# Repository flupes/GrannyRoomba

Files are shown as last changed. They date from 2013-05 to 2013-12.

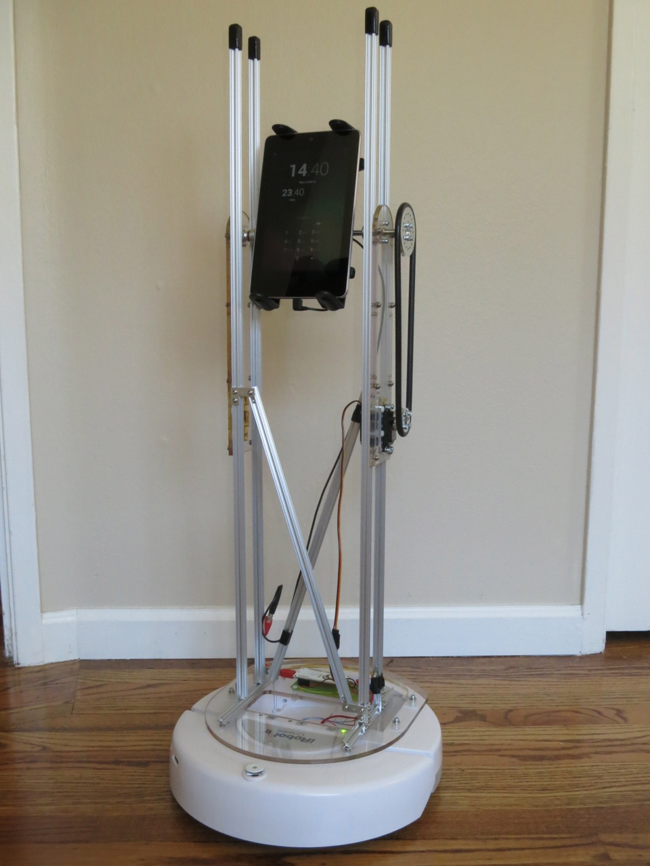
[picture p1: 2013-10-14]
hw/pics_2013-10-14/gr_overview.jpg

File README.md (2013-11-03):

GrannyRoomba or Telepresence Roomba for Grandma
===============================================

The idea of this project is to develop a simple and inexpensive telepresence robot to improve the Skype experience of a grandmother with her grandchild.

On Columbus Day 2013, the system performed successfully a first robotic video conference from France to California!
The system still need improvements, but the concepts are in place.

Quick facts:
  - The mobile base uses a [Roomba Create](http://www.irobot.com/us/learn/Educators/Create.aspx)
  - The custom super-structure uses a tilt mechanism actuated with a servo
  - Nexus-7 Android (gen 1) tablet runs the robot software
  - [IOIO-OTG](https://github.com/ytai/ioio/wiki) board interfaces the tablet with the hardware
  - Messaging is defined using Google [Protocol Buffers](https://developers.google.com/protocol-buffers/)
  - Communication relies on the [ZeroMQ](http://zeromq.org/) library (more precisely [JeroMQ](https://github.com/zeromq/jeromq))

You can look at some pics from the [Wiki page](https://github.com/flupes/GrannyRoomba/wiki/GrannyRoomba-Wiki-Home).

History of this project is available in the [project.org](https://github.com/flupes/GrannyRoomba/blob/master/project.org) file.

License:
  - The software part (code) of GrannyRoomba is released under [GPLv3](http://www.gnu.org/licenses/gpl-3.0-standalone.html).
  - The hardware part (drawings, electronics, etc.) is released under a <a rel="license"
    href="http://creativecommons.org/licenses/by-sa/3.0/deed.en_US">Creative
    Commons Attribution-ShareAlike 3.0 Unported License</a>

Do you want to help? Do you like the name or find it ridiculous? Contact me!

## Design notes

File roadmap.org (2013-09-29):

* Iteration 1: proof of concept
** Goal
   Obtain a system that allows to command wirelessly the Roomba and Tilt-Servo from
   the PC, this while running Skype on the tablet.
** Work items
*** DONE Create a basic serial "driver" to command the Roomba
*** DONE Test a IOIO Service running together with Skype
*** DONE Setup and read the telemetry from the Roomba
*** DONE Test commanding Roomba from IOIO
*** DONE Build and test ZeroMQ from PC to Android
*** DONE Use slf4j for logging with implementation of log4j on PC and slf4j-android on Android
*** DONE Configure and test JeroMQ on PC and on Android
*** DONE Create a board to power the IOIO from the Roomba and provide communication lines
*** DONE Find a realistic Android debug solution with the IOIO
    - System for Android Virtual Device that works:
      - use IOIO bridge to allow the AVD talk to the IOIO connected to the PC
      - use adb port forwarding to bridge the localhost port required by
        zeromq to the AVD
      - use regular ADB to debug
    - Still no success using the Nexus-7:
      - it should work with ADB over wifi and using the IOIO as an
        Open-Accessory device, but the way I trigger ADB over wifi still
        requires "USB Debug" enabled... I think the Nexus need to be
        rooted to go otherwise
*** DONE Create protocol-buffer messages to support Locomotion and SingleAxis commands
*** DONE Create framework to run the client / server system
*** DONE Create the clients and servers for locomotion and single axis
*** DONE Create a Eclipse workspace where JeroMQ, slf4j, IOIO, the generic part of the project code and the specific Android app code is happy
*** DONE Create a simple UI to command the robot (keyboard based)
*** DONE Create a framework to start the GrannyRoomba controller as a Android Service
* Iteration 2: stabilize the system and fill huge gaps
** Goal
   Make the system more usable, mostly by working on the lifecycle of the
   application. Some critical features also need to be implemented to
   avoid breaking the Roomba: bump detection (and position drive to backup)
** Work items
*** TODO Implement position drive
*** TODO Implement safe guarded locomotion (using bumpers)
*** TODO Refine the start/stop of the system and lifecyle of the GrannyRoomba servive
* Iteration 3: clean up the system and document
* Iteration 4: add some features
** Goal
** Work items
*** TODO Implement a joystick controller
*** TODO Create a broker service to allow bi-directional communication between to hosts, each between firewalls

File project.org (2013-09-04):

##+TITLE: GrannyRoomba Project
#+AUTHOR: Lorenzo Flueckiger
#+STARTUP: showall

* GrannyRoomba Project

** Goal
Develop a simple and cheap telepresence robot to improve the Skype
experience of a grandmother with her grandchild K.

** Rationale

K. does a video conference with his overseas Grand-Ma almost every
week. It is one way to keep this important relationship active. K. loves
to show in great details his latest creations (essentially Legos;-) and
they occasionally play roles.

We initially were doing Skype sessions with a laptop. We often had to move
the laptop from the table to the play area and back. Then we moved to
Skype on a smart-phone. This bring more mobility and allow to show better
details of the constructions. However it requires a person holding the
phone. Since K. needs his hands to manipulate toys, this role ends up to
Daddy. For this, we most of the time use the back camera to let the phone
holder point the camera precisely to the details of the action. This mode
is great for close up but we loose Grand-Ma' face. In addition, it is much
more demanding for the Dad than the laptop system which can stay
unattended for longer periods.

The system let Grand-Ma completely dependent of the skills of the phone
holder to keep up with the action and avoid to become dizzy. I knew that
Mobile Remote Presence (MRP) systems are designed to improve remote
interactions between people (see [[http://scholar.google.com/scholar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][Takayama HRI2011]] for a use case close to
this one) but was seeing this mostly as something on the fringe of my own
robotic domain. However when visiting our neighbor [[http://www.willowgarage.com/pages/research/human-robot-interaction][Willow Garage]] I
suddenly realized that I could use one of these MRP at home to have
Grand-Ma managing her own projection into K. world!

Of course, a nice professional MRP is out of my budget, but this gave me
the idea to tinker with a Roomba and an Android tablet...

** Requirements

GrannyRoomba should provide the remote user a camera with pan/tilt
controls, mounted on mobile base. The robot will only work indoors. The
tilt control is critical to offer close-up views. The pan
degree-of-freedom can be realized by the mobile base.

There should be a simple to use interface to control the various movement
of the camera, and the system should work between computers on different
networks.

The system should provide a video stream of the remote user on the
GrannyRoomba.

** Concepts

*** Computing and screen
First, I do not want to have to deal with any video and audio link between
two private homes separated by a continent plus an ocean. So the video and
audio link will still be handled by Skype or iChat/FaceTime. This implies
to use a computer system that supports well this applications, has a
screen and is lightweight. So an Android tablet (a phone screen is a little
bit too small to personalize Grand-Ma) is very tempting. A small Android
tablet like the [[http://www.google.com/nexus/7/][Nexus-7]] would provide:
 - all the necessary computing power
 - a nice screen to show Grand-Ma face
 - a camera to feed the video stream to the remote user
 - a wifi connection to connect to the home router and the rest of the world
 - extra sensors (compass and accelerometer+gyro) that we could use to
   improve the situation awareness of for the remote user
 - an open platform nice to hack

*** Robotic mobile base
Second I need a mobile base to support Grand-Ma virtual head. The height
of a MRP plays a critical role in user interactions. Unfortunately, it is
not realistic to build for this project a mobile robot that can support a 1.5m mast.
However a virtual head hovering between 30cm to 50cm from the
ground will be plenty: K. play mostly happens on the floor or on a large
shelf (what is the right word here?) 35cm height. If the action moves on a
table, K. will have to lift Grand-Ma to let her roll on the table... To
minimize the hardware work and finally use a gadget that only gather dust
in the attic, my old Roomba seems all designated for the job. This is a
pretty old [[http://www.irobot.com/us/Support/For_Home/Roomba_400_Resources/Anatomy.aspx][Roomba 400 Series, Discovery model]], that fortunately already
has the serial port socket. In theory this Roomba should provide a robust
mobile base with a nice control system documented in the
iRobot Roomba Serial Command Interface (SCI) Specification:
  - [[http://www.irobot.com/images/consumer/hacker/Roomba_SCI_Spec_Manual.pdf][broken link from iRobot]]
  - [[./refdocs/Roomba_SCI_Spec_Manual.pdf][local copy of the file]].

*Update:*
It turned out that I never could get the Roomba 400 to work, so I switched
to the iCreate (see Update section).

The Roomba Create has a different set of capabilities and access to more
internal information. The Create Open Interface is described in:
  - [[http://www.irobot.com/hrd_right_rail/create_rr/create_fam/createFam_rr_manuals.html][online version of the specification]]
  - [[./refdocs/Create_OpenInterface_v2.pdf][local copy]] just in case the iRobot link also disappears

*** Android interface with hardware
Communication between the tablet and the Roomba can happen in different
ways. The more simple probably would some existing Bluetooth-Roomba
adapter like [[https://www.sparkfun.com/products/10980][Rootooth]]. However it would only provide control to the
Roomba and not support other input/output necessary for a Pan/Tilt
system. So instead I will try a [[https://www.sparkfun.com/products/10748][IOIO board]] which provides incredible I/O
capabilities to an Android system.

*** Pan/tilt system
Because the Roomba can perform nice point turns, only a tilt system for
the camera is required. Note that in fact the whole tablet need to be
tilted since the plan is to use the front facing camera. This will require a
sort of gimbal, probably actuated with a servo motor. The servo motor can
be easily managed by the IOIO.

Note also that initially I would have loved be able to vary the height of
the tablet/camera to provide a better view of objects depending their
location. Again the IOIO would allow this extra control, but the mechanics
will become a little bit more involved. So maybe this a a good follow on
project next generation of GrannyRoomba.

*** Device drivers

ROS? RoombaCMD, custom?

*Update:*
Since I did not proceed with ROS because its complexity and very partial
support on Android, I went with my custom Roomba interface. The commanding
part is pretty trivial, but the telemetry listening was slightly more
challenging. It seems function and serve my need for now.

*** User interface

A physical interface like a joystick would be great, but I think that this
mode of operation could not work because of the time delay between the
remote control station and the robot.

So the UI will probably end up being some sort of web page with control
buttons (need to learn more on this topic).

*** Communication

For maximum accessibility, the best would probably to run a web server on
the Android tablet (is this possible) with a port mapping on the home
router. This means I will have to learn about web protocols...

[[http://www.rosbridge.org/doku.php][rosbridge]] and websockets?

rosjava development does not seems very active, and with the disappearance
of Willow Garage, I have some doubt about the future support for
ROS. Since my project is moving extremely slowly, I need a stable long
term solution;-)

[[https://code.google.com/p/i-jetty/][i-jetty]] seems the simple solution to deploy a web-server on an Android
system.

The web-based approach seems a little bit costly in time with my current
knowledge of the domain. I will look at a more bare-bone solution with [[http://www.zeromq.org/][0MQ]]
for the transport layer and [[https://developers.google.com/protocol-buffers/][Protocol Buffers]] for the data description and
serialization.

*Update:*
The first experiments using ZeromMQ native C libraries and the Java
bindings worked correctly after quite a bit of tinkering. An advantage of
my project going so slow is that in the mean time, [[https://github.com/zeromq/jeromq/wiki][JeroMQ]] matured, and I
adaopted it. So currently GrannyRomba uses:
  - JeroMQ for the communications layer
  - Protocol Buffer for the message definition/encoding

** Notes / Links

http://hackingroomba.com/projects/build-a-roomba-serial-tether/

http://www.dprg.org/projects/2009-07a/

Open Source alternative to Skype?
[[https://jitsi.org/][jitsi]]

* Updates

- [2013-08-31 Sat] Finally all the different components are working in
  harmony: the first prototype of a iCreate Roomba with a Nexus-7 tablet
  mounted on a tilt system can be driven by K. inside the house. It uses
  JeroMQ for the communication, Google protocol-buffers to encode the
  messages and slf4j for logging. The Android tablet talk with the Roomba
  and the servo using the IOIO-OTG which is powered (using a regulator)
  from the Roomba.
- [2013-05-04 Sat] Performed some initial testing with the IOIO OTG and the
  Roomba Discovery: absolutely no success! The Roomba seems death to all
  the attempts to communicate with it. Out of frustration, I purchased a
  Roomba Create, and the same IOIO rig seems to talk fine with it. So this
  is an extra expense, but I also get a much nicer platform that will easy
  the hardware integration. The Roomba Create also has a extended
  "Open-Interface". And finally, the cost is minimal since it uses the APS
  battery and charger from the old Roomba (~$100 saved).
- [2013-04-20 Sat] Starting to work again on the project after 3 months
   lost due to a forced moving that had a double impact:
  - The nice play-area with raised platform does not exist at our new
    place, meaning that a 2 feet high GrannyRoomba will not
    have the ideal dimensions to play. It can still be used for ground
    level play, but not see something on a normal table.
  - A lot a energy and time was wasted to do non creative chores.

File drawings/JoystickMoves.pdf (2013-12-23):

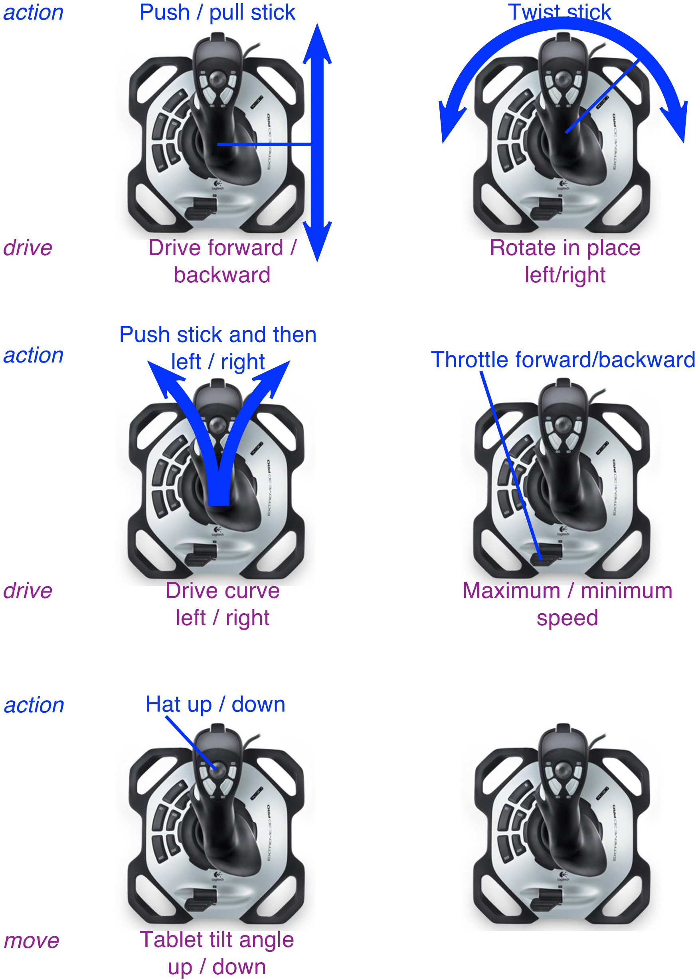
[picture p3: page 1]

action | Push / pull stick
drive | Drive forward / backward
| Push stick and then left / right

Hat up / down

action

drive

action

move

Drive curve
left / right

Tablet tilt angle
up / down

Throttle forward/backward

Maximum / minimum
speed

Twist stick

Rotate in place
left/right

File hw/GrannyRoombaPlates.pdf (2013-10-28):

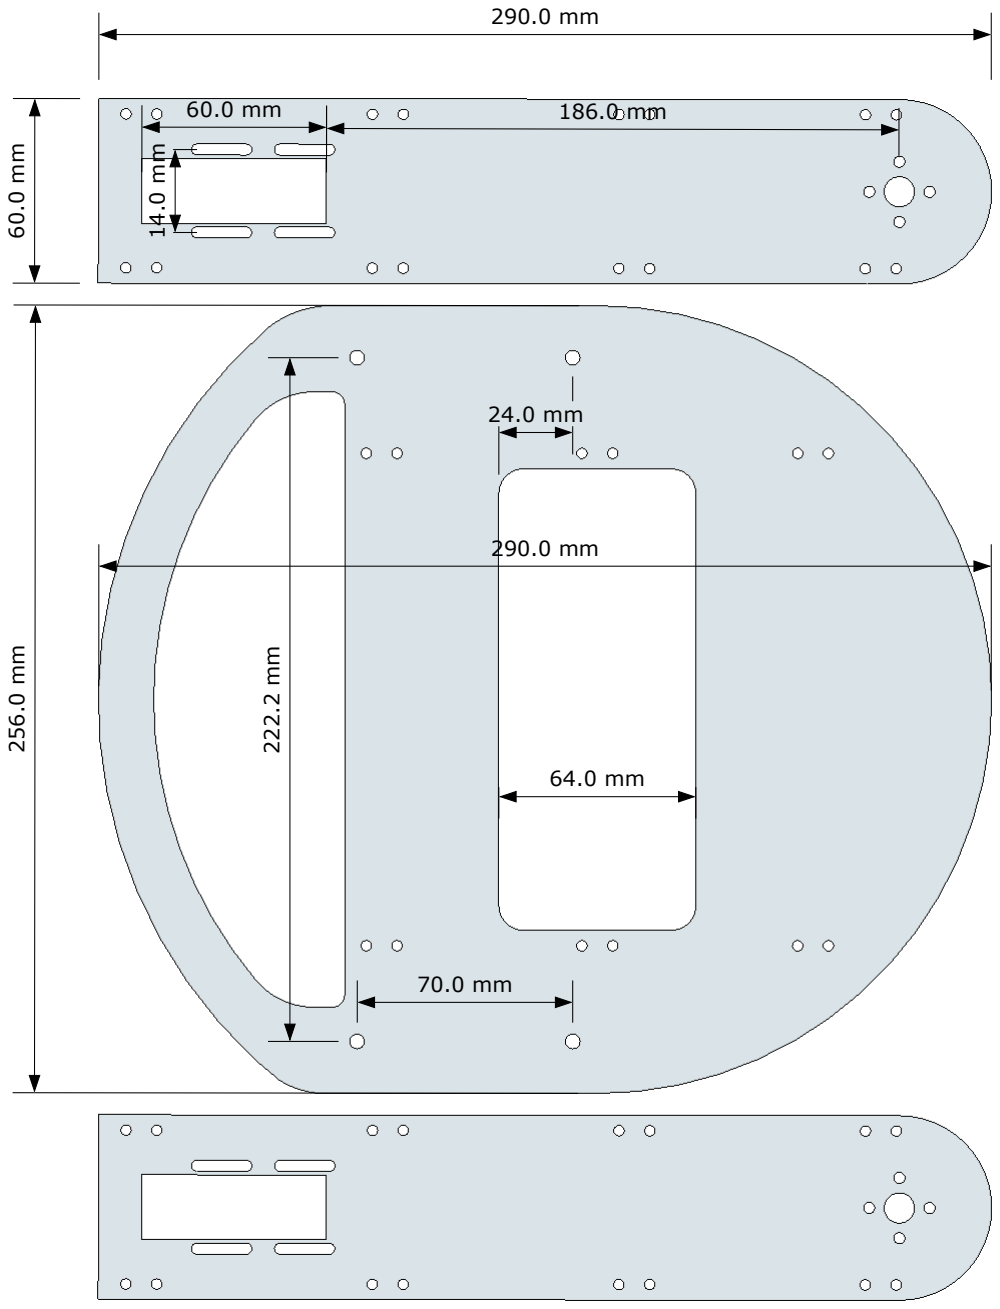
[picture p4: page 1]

60.0 mm

290.0 mm

290.0 mm

256.0 mm

70.0 mm

222.2 mm

60.0 mm | 186.0 mm

64.0 mm

14.0 mm

24.0 mm

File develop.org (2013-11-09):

* Eclipse setup
** Download and install Eclipse Standard (4.3)
   http://www.eclipse.org/downloads/
** Download and install the Android SDK
   http://developer.android.com/sdk/installing/index.html
** Install the Android Eclipse plugin
   http://developer.android.com/sdk/installing/installing-adt.html
** Install the Apache Logging plugin
   - Add the Orbit Repository
   http://download.eclipse.org/tools/orbit/downloads/
   - Install "Apache Jakarta log4j Plug-in"
#+BEGIN_COMMENT 
*this method is not satisfactory and is now replaced by getting slf4j from git*
Install logback and slf4j from from the qos.ch repository
http://logback.qos.ch/p2/
Note: I could not get the version of logback from Orbit to work, so the
process below is replaced by the above qos...
  Add the Orbit repository
  http://download.eclipse.org/tools/orbit/downloads/
  Install from Orbit:
    - SLF4J API
    - Logback Core
    - Logback Classic
#+END_COMMENT
** Install the Protobuf-DT plugin
   - Instructions at:
     https://code.google.com/p/protobuf-dt/
   - Install Xtext from (version 2.4.2 seems to please Eclipse and protobuf!)
     http://download.eclipse.org/modeling/tmf/xtext/updates/composite/releases/
   - Install protobuf-dt from:
     http://protobuf-dt.googlecode.com/git/update-site
   - In Preferences -> Protocol Buffer -> Compiler:
     - Main tab
       - set the path for "use protoc in path"
       - select compile .proto files on save
     - Option tab
       - select generate Java
       - Java Output Directory : gen
   - Add an association between the *.proto files and the protobuf editor
** Install findbugs
   - Install findbugs from the following repo:
     http://findbugs.cs.umd.edu/eclipse
   - Tutorial at:
     http://www.vogella.com/articles/Findbugs/article.html
** Install Eclipse MAT (Memory Analyzer
   - Install MAT from the following repo:
     http://download.eclipse.org/mat/1.3/update-site/
   - Tutorial at:
     http://www.vogella.com/articles/EclipseMemoryAnalyzer/article.html
* Install GrannyRoomba dependencies
#+BEGIN_SRC bash
# IOIO
cd /Users/Shared/git
git clone https://github.com/ytai/ioio.git
cd ioio
git checkout tags/App-IOIO0330
# JeroMq
cd ..
git clone https://github.com/zeromq/jeromq.git
# SLF4j
cd ..
git clone http://github.com/twwwt/slf4j.git
cd slf4j
git checkout 77a28b4 -b v_1.7.5
export JAVA_HOME=`/usr/libexec/java_home`
cd slf4j-api
mvn install
cd ../slf4j-log4j12
mvn install
cd ../slf4j-android
SDK=/Users/Shared/pkgs/android-sdk-macosx_r22.2
export PATH=${SDK}/tools:${SDK}/platform-tools:${PATH}
export ANDROID_HOME=${SDK}
mvn install
#+END_SRC
* GrannyRoomba Workspace creation (new)
** Configure Eclipse ADK (if not already done)
   - Eclipse -> Preferences -> Android
   - Set the "SDK Location":
     /Users/Shared/pkgs/android-sdk-macosx_r22.2
** Define path to dependencies
   Eclipse -> Preferences
   General -> Workspace -> Linked Resources
   New Path Variable
   GR_PKGS_ROOT : /Users/Shared/git
** Clone the GrannyRoomba repository
** Import the project dependencies
   - File -> Import -> Git -> Projects from Git
   - Existing local repository
   - Select the GrannyRoomba clone and then:
     - IoioLibAndroid
     - IoioLibPC
     - jeromq_notests
   - Check that everyting builds correctly
** Import the GrannyRoomba projects
   - Same process than above (can be done all at 
     once in fact)
   - Select all the org.flupes.ljf.grannyroomba.* projects
     The remaining projects are tests and experiments that
     can also be imported
* GrannyRoomba Workspace creation (old)
** Download the v3.3 (for OTG) of the  IOIO Software from:
   https://github.com/ytai/ioio/wiki/Downloads
   - Unpack under /Users/Shared/pkgs/App-IOIO330
   - File -> Import -> General -> Existing Projects into Workspace
   - Select All but IOIOlibBT and IOIOLibAccessory
** Clone in Eclipse the GrannyRoomba repo (with EGit)
   https://github.com/flupes/GrannyRoomba.git
   - clone the repo under /Volumes/ljfdev/git/GrannyRoomba
   - import the projects under thirdparty:
     - jeromqLibAndroid
     - slf4jLibAndroid
   - import all the projects under code
** JeroMQ for PC
   - From git: https://github.com/zeromq/jeromq.git
   - Import from Maven to Eclipse
* Android Platform
** ADT
http://developer.android.com/sdk/installing/bundle.html
** NDK
http://developer.android.com/tools/sdk/ndk/index.html
** APIs Levels
http://developer.android.com/guide/topics/manifest/uses-sdk-element.html#ApiLevels
** Direct Links
*** API Guide
    http://developer.android.com/guide/components/index.html
** Connect to Android Device over TCP
http://stackoverflow.com/questions/2604727/how-can-i-connect-to-android-with-adb-over-tcp
#+BEGIN_SRC
# connect device with USB
adb tcpip 5555
# disconnect usb
adb connect 172.16.0.39:5555
# to go back to usb mode
adb usb
#+END_SRC
http://developer.android.com/tools/help/adb.html#forwardports
*** Processes and threads
http://developer.android.com/guide/components/processes-and-threads.html
** When things do not work!
*** Some classes are not resolved
    - Make sure that all the code is compiled with Java 1.6 (some DeX
      errors shoud show up in the console if not)
    - Make sure that all the dependent projects are also exported
* IOIO
** [[https://github.com/ytai/ioio/wiki][IOIO Wiki]]
** Using target projects for both PC and Android
IOIO provides 2 projects libraries:
  - IOIOLibPC, to build project targeted to PC (Mac)
  - IOIOLibAndroid, to build projects targeted to Android
Theses two projects share common code that is part of the IOIOLib
directory. However the dependency is kind of reversed: for example the
IOIOLib (supposedly generic code), relies on ioio.lib.spi.Log which is
defined in the target projects!

This is working fine for single projects built for a specific target (PC
or Android). But it breaks down if you want to build a project (let say
"common") that relies on the IOIO API, and that you want to use this
project in other projects targeted to either PC or Android: it is not
possible to have "common" just depend on the IOIO API without pulling the
target platform specific code!
#+BEGIN_SRC ditaa
Desired:
--------
         Prog_PC     App_Android              
            |             |
    +-------+---+     +---+------+
    |       |   |     |   |      |
IOIO_LibPC  |  CommonLib  |  IOIO_LibAndroid
            |             |
            +----+--------+
                 |
              IOIO_API <=== This is not feasible due to the current
                            architecture of the IOIO projects

Workaround:
-----------
     Prog_PC            App_Android              
        |                    |
        |                    |
    CommonLib <- - - - - CommonLib_Android (separate project sharing
        |       linked       |              the same source tree but
        |      ressource     |              with different settings)
    IOIO_LibPC           IOIO_LibAndroid
#+END_SRC
** Running IOIO connected to an Android Virtual Device
   https://github.com/ytai/ioio/wiki/IOIO-Bridge
** Setup to run on the AVD
#+BEGIN_SRC bash
adb forward tcp:6666 tcp:3333
adb forward tcp:7777 tcp:4444
/Users/Shared/pkgs/IOIOBridge/ioiobridge /dev/tty.usbmodem1411
#+END_SRC
** Debug when running on the Nexus7
   *This seems to be impossible with a non-rooted phone*
   IOIO can be use either:
   - over ADB -> it is not possible to debug anymore
   - over OpenAccessory -> USB debugging need to be turned off
     (preventing adb over wifi).
     This post seems to confirm my findings:
     http://stackoverflow.com/questions/19642583/how-to-use-adb-tcpip-without-usb-debugging-enabled
* Protobuf
https://developers.google.com/protocol-buffers/

* JeroMq for PC under Eclipse
  - Checkout the repo (command line) from:
  https://github.com/zeromq/jeromq.git
  - Import the projects from the repo with Eclipse
  - Convert to plugin (right click menu)
* JeroMq for Android under Eclipse
*Only if not using the pre-packaged project under thirdparty*
** Get the source code for PC
   git clone https://github.com/zeromq/jeromq.git
   - File -> Import -> Maven -> Existing Maven projects
   - Rename the project as jeromqLibPC
** Create a new Android Library
   - File -> New -> Others -> Android -> Android Application Project
   - name: jeromqLibAndroid, minimum SDK: 8, target SDK 17
   - Configure Project tab: Uncheck all but "Mark this project as library"
   - Copy the 4 packages under src/main/java in jeromqLibPC to the src
     folder under jeromqLibAndroid (org.jeromq, org.zeromq.codec,
     org.zeromq, zmq)
   - In the Manifest, change the package name to org.zeromq
* Basic tests that work
** Testing jeromq server on Android and client on PC
#+BEGIN_EXAMPLE
# launch the server on the virtual device:
/JeroMqAndroid/AndroidManifest.xml

# connect to the Virtual Android Device which runs a server on port 8888:
adb forward tcp:6666 tcp:8888

# run the following exec on the PC
/JZeroMqPC/src/org/flupes/grannyroomba/test/zmqpc/helloclient/hwclient.java
#+END_EXAMPLE
* Creating the Eclipse projects required for GR
** slf4j
*** Clone the git repo
    https://github.com/qos-ch/slf4j.git
*** Import the Maven projects into Eclipe:
    - need a list of required projects here
*** Modify the slf4j-api.pom.xml to remoe the error
diff --git a/slf4j-api/pom.xml b/slf4j-api/pom.xml
index 63a489c..49250ef 100644
--- a/slf4j-api/pom.xml
+++ b/slf4j-api/pom.xml
@@ -67,12 +67,15 @@
         <groupId>org.apache.maven.plugins</groupId>
         <artifactId>maven-antrun-plugin</artifactId>
         <executions>
+            <ignore />
+            <!--
           <execution>
             <phase>process-classes</phase>
             <goals>
              <goal>run</goal>
             </goals>
           </execution>
+           -->
         </executions>
         <configuration>
           <tasks>
** jeromq
*** Clone the git repo
    https://github.com/zeromq/jeromq.git
*** IMport the Maven project into Eclipse
*** Remove the src/test directory
*** Modify the pom.xm to get rid of the junit dependency
diff --git a/pom.xml b/pom.xml
index 1729d45..d68ae95 100644
--- a/pom.xml
+++ b/pom.xml
@@ -42,12 +42,6 @@
         </exclusion>
       </exclusions>
     </dependency>
-    <dependency>
-      <groupId>junit</groupId>
-      <artifactId>junit</artifactId>
-      <version>4.8.2</version>
-      <scope>test</scope>
-    </dependency>
   </dependencies>
   <build>
     <plugins>
** ioio
*** Clone the git repo
    https://github.com/ytai/ioio.git
*** Import "Projects from Git" into Eclipse
    - a list here is needed
*** Resolve the libraries path for IOIOBridge
* ZeroMQ for Android
*deprecated now that we use JeroMQ*
http://www.zeromq.org/build:android
#+BEGIN_SRC bash
# Create the standalone toolchain
$NDK/build/tools/make-standalone-toolchain.sh \
    --system=darwin-x86_64 \
    --platform=android-14 \
    --install-dir=/Users/Shared/pkgs/android-toolchain_14

# Configure and build ZeroMQ
export OUTPUT_DIR=/Users/Shared/android
cd /Users/Shared/android/src
tar xzvf ../../tarballs/zeromq-3.2.2.tar.gz
cd zeromq-3.2.2
./configure --enable-static --disable-version --host=arm-linux-androideabi \
    --prefix=$OUTPUT_DIR LDFLAGS="-L$OUTPUT_DIR/lib" CPPFLAGS="-fPIC \
    -I$OUTPUT_DIR/include" LIBS="-lgcc"
# What to do with --disable-shared ???
make
make install

# Configure and build jzmq
cd /Users/Shared/android/src
git clone https://github.com/zeromq/jzmq.git
cd jzmq
export OUTPUT_DIR=/Users/Shared/android
export JAVAC="javac -source 5 -target 5"
./autogen.sh
# Edit the configure script (does not locate correctly the java headers)
15929,15930c15929,15930
< case "$host_os" in
<         darwin*)        _JTOPDIR=`echo "$_JTOPDIR" | sed -e 's:/[^/]*$::'`
---
> case `uname -s` in
>         Darwin*)        _JTOPDIR=`echo "$_JTOPDIR" | sed -e 's:/[^/]*$::'`
./configure --enable-static --disable-version --host=arm-linux-androideabi \
    --prefix=$OUTPUT_DIR --with-zeromq=$OUTPUT_DIR
make
make install

# Reduce size (remove debug info only)
cd $OUTPUT_DIR/lib
arm-linux-androideabi-strip -g libzmq.a libjzmq.a
#+END_SRC
* Random Stuff
** How to add the license headers:
   - Test:
copyright-header -n --license GPL3 --copyright-holder "Lorenzo Flueckiger"
--copyright-year=2013 --copyright-software="GrannyRoomba"
--copyright-software-description "Telepresence robot based on a Roomba
and Android tablet" --add-path code
   - Perform:
copyright-header --license GPL3 --copyright-holder "Lorenzo Flueckiger"
--copyright-year=2013 --copyright-software="GrannyRoomba"
--copyright-software-description "Telepresence robot based on a Roomba and
Android tablet" --add-path
code/org.flupes.ljf.grannyroomba/src:code/org.flupes.ljf.grannyroomba.net/src/:code/org.flupes.ljf.grannyroomba.hw/src/:code/org.flupes.ljf.grannyroomba.hw_pc/src/:code/org.flupes.ljf.grannyroomba.controller/src/:code/org.flupes.ljf.grannyroomba.pctests/src/
--output-dir ./

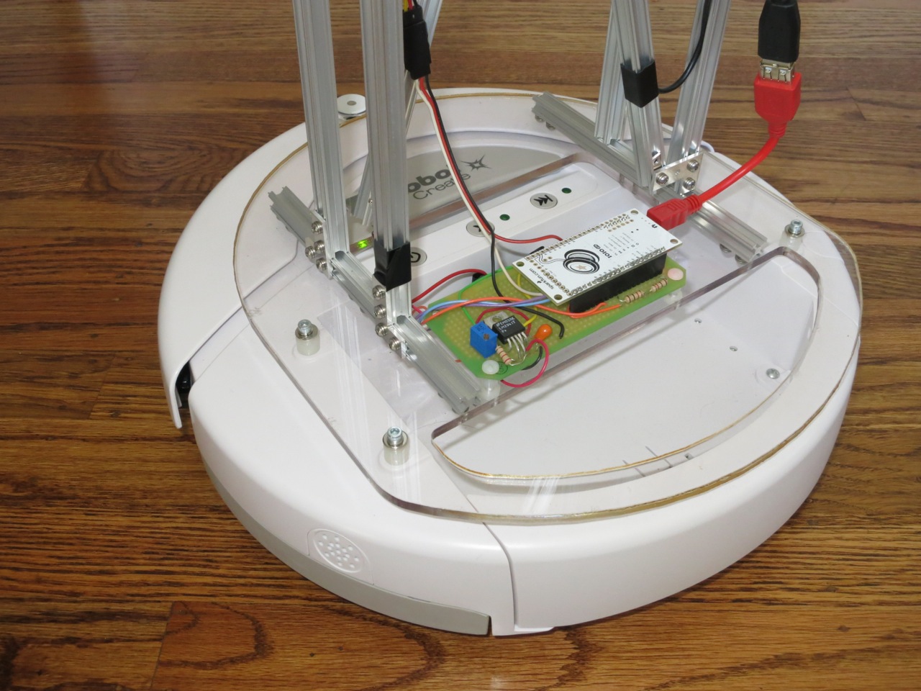
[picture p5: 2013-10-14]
hw/pics_2013-10-14/gr_board.jpg

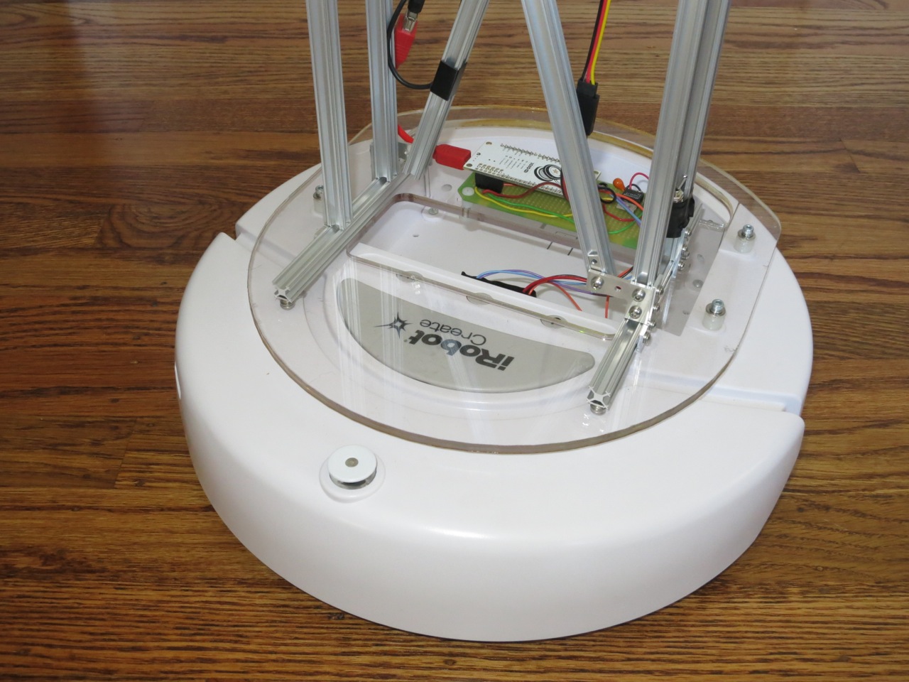
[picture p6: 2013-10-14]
hw/pics_2013-10-14/gr_base.jpg

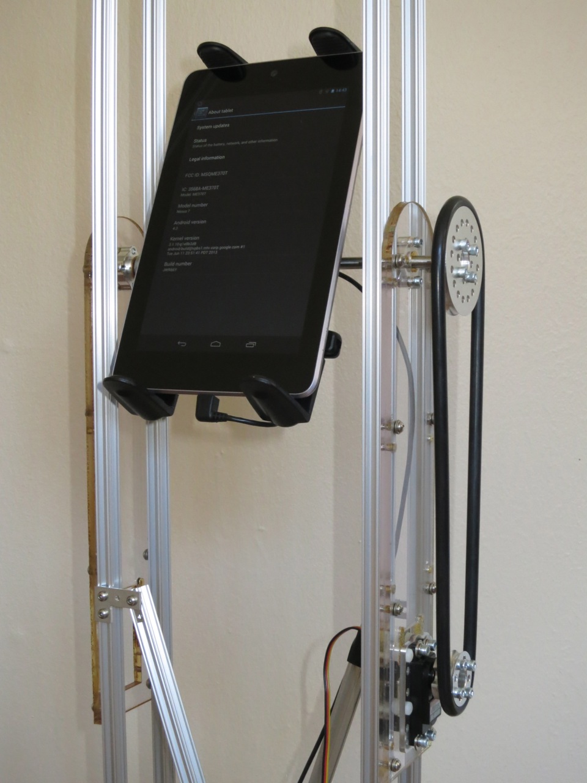
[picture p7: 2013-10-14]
hw/pics_2013-10-14/gr_tilt.jpg

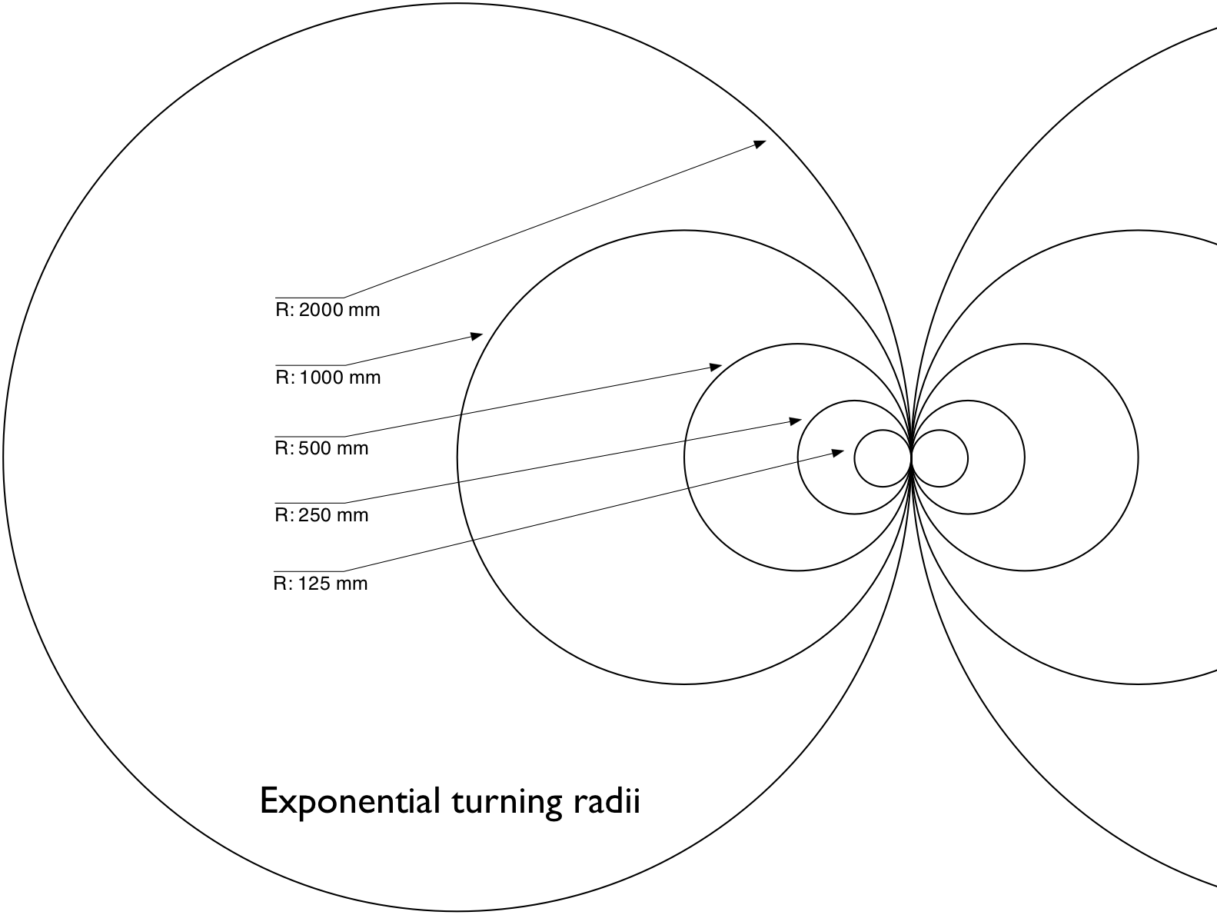
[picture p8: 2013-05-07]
drawings/TurningRadius.png

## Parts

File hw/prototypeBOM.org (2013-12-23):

* First GrannyRoomba Prototype Bill of Material

The BOM for the first prototype has not been optimized for price, but for
simplicity of construction with a maximum of COTS components

|-----------------------------------------+----------+------------+-----------+------------+--------+--------|
| Part Name                               | Quantity | Provider   | Reference | Unit Price |   Cost | Remark |
|-----------------------------------------+----------+------------+-----------+------------+--------+--------|
| High-Torque/180 deg Standard Size Servo |        1 | Adafruit   | 1142      |      19.95 |  19.95 |        |
| 0.770 Standard Hub Horn Futaba 25T      |        1 | ServoCity  | 525132    |       4.99 |   4.99 |        |
| 2 inch Smooth Hub Pulley                |        1 | ServoCity  | 615134    |       7.99 |   7.99 |        |
| 1 inch Smooth Hub Pulley                |        1 | ServoCity  | 615130    |       5.99 |   5.99 |        |
| 1/4 inch Bore Clamping Hub              |        1 | ServoCity  | CH250-770 |       7.99 |   7.99 |        |
| 3/8 inch Bore Set Screw Hub             |        2 | ServoCity  | H375-770  |       4.99 |   9.98 |        |
| 1/4 inch x.500 inch                     |        2 | Servocity  | AGB-A2-10 |       1.45 |    2.9 |        |
| Clamp-on Shaft Collar, for 1/4" Dia.    |        2 | McMaster   | 9961K13   |       2.60 |    5.2 |        |
| 1/4 inch x8 inch Precision Shaft        |        1 | ServoCity  | SS250-8   |       2.69 |   2.69 |        |
| Urethane O-Ring Round Belt, Clear,      |        1 | McMaster   | 3044K603  |       3.79 |   3.79 |        |
| 1/8" Diameter, 21" Outer Circle         |          |            |           |            |      0 |        |
| Base plate and side plates              |        1 | BigBlueSaw |           |      71.25 |  71.25 |        |
| 10mm profile x 800mm (4 + 2*1/2)        |        5 | Microrax   |           |          8 |     40 |        |
| 10mm profile x 160 (2 base + 1 up)      |        3 | Microrax   |           |        1.6 |    4.8 |        |
| Small hardware (rough estimate)         |        1 |            |           |         12 |     12 |        |
| Need to detail the line above           |          |            |           |            |      0 |        |
|-----------------------------------------+----------+------------+-----------+------------+--------+--------|
|                                         |          |            |           |      Total | 199.52 |        |
|-----------------------------------------+----------+------------+-----------+------------+--------+--------|
#+TBLFM: $6=$2*$5::@18$6=vsum(@2$6..@17$6)

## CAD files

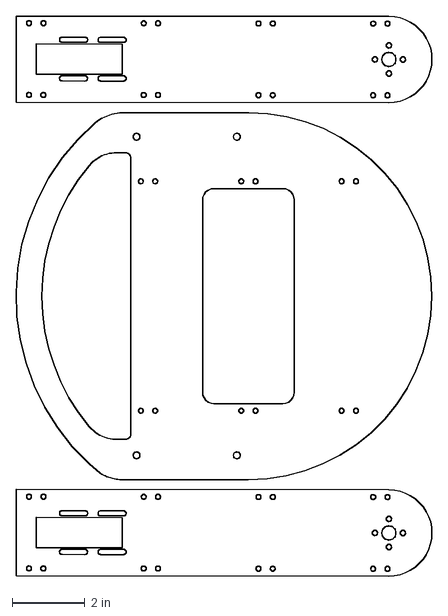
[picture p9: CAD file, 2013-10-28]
hw/GrannyRoombaPlates.dxf
11.4 x 15.4 in

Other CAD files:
hw/GrannyRoombaPlates.skp

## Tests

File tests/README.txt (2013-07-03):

Playground for some tests and experiments that are not part of the main code base (in src)

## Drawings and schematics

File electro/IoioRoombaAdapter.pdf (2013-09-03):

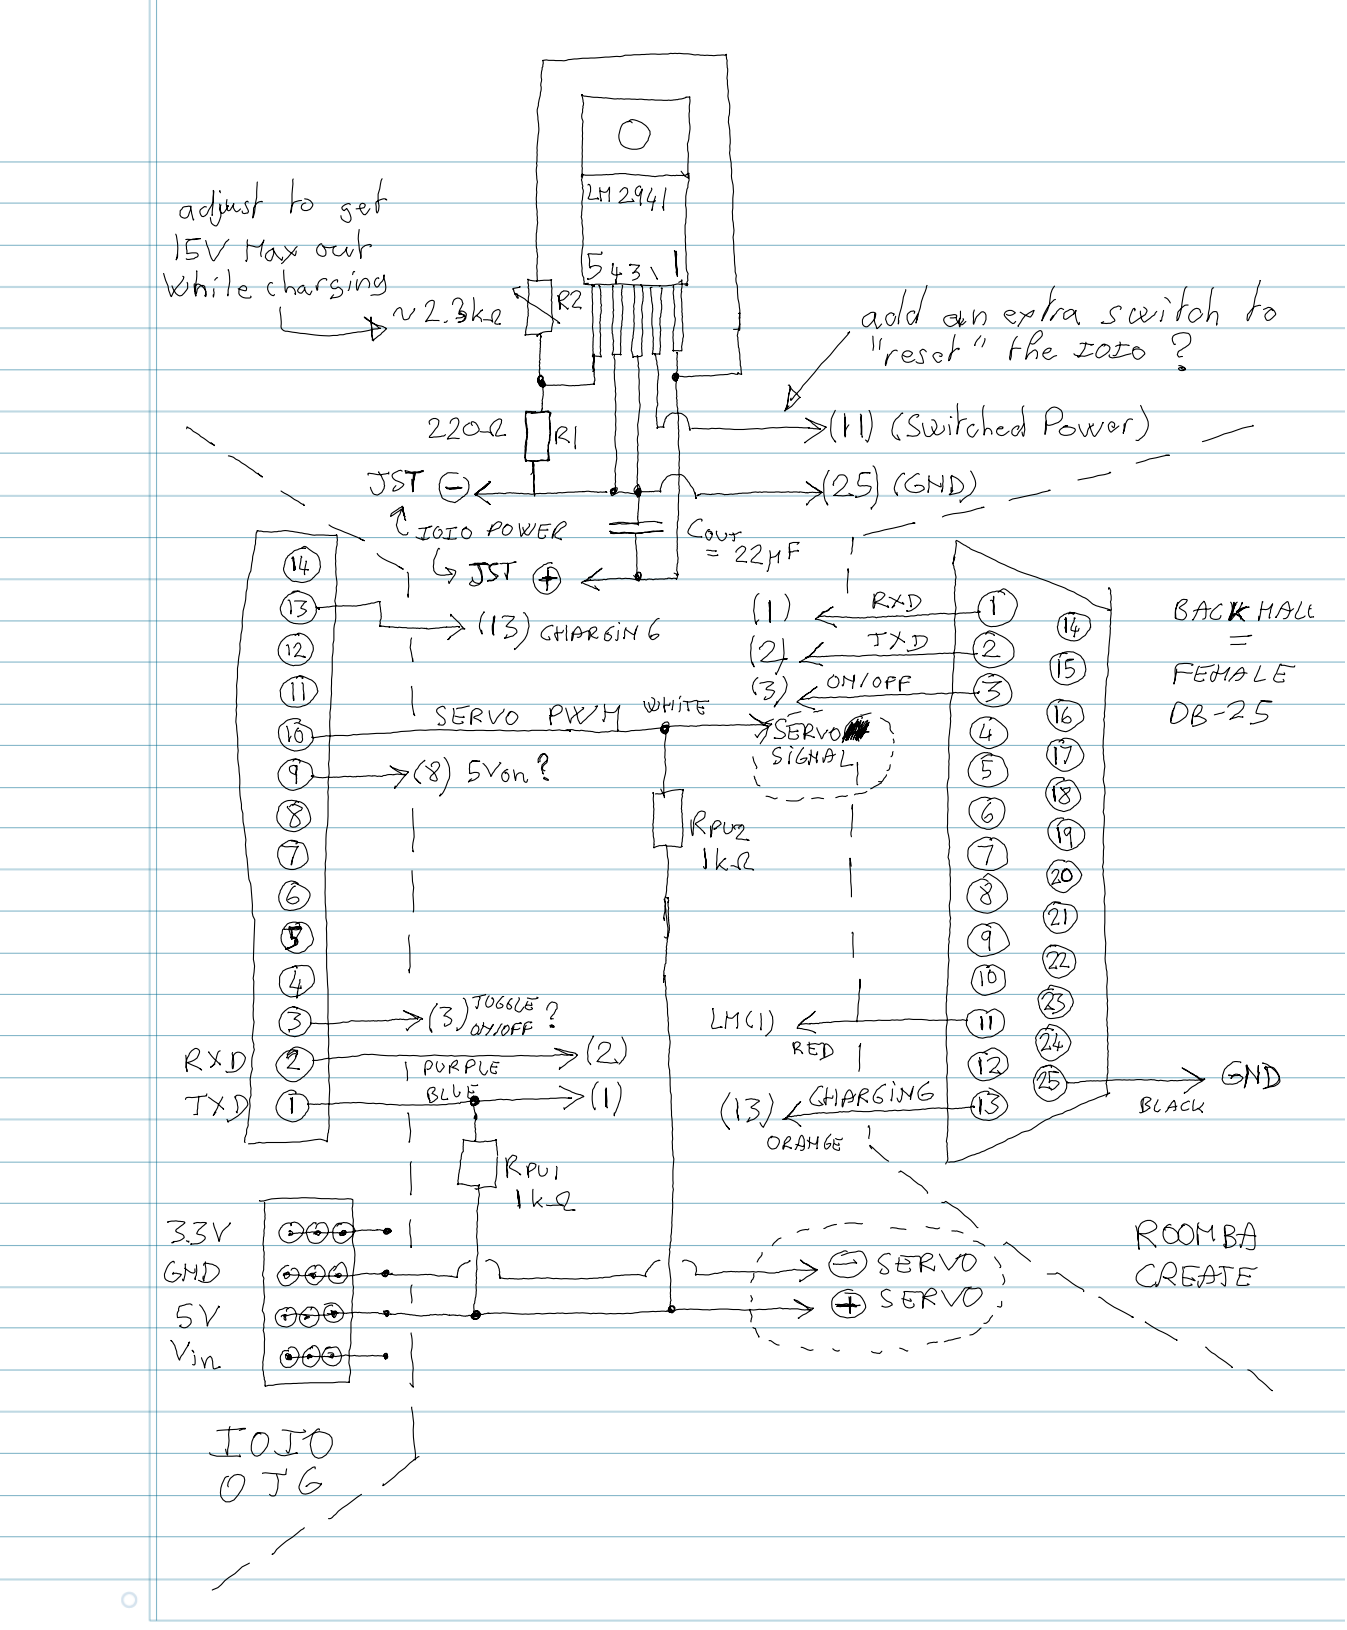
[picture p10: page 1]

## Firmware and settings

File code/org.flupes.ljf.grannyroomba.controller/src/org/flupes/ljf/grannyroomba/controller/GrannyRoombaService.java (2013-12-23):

/*
 * GrannyRoomba - Telepresence robot based on a Roomba and Android tablet
 * Copyright (C) 2013 Lorenzo Flueckiger
 *
 * This file is part of GrannyRoomba.
 *
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
 * You should have received a copy of the GNU General Public License
 * along with GrannyRoomba.  If not, see <http://www.gnu.org/licenses/>.
 */

package org.flupes.ljf.grannyroomba.controller;

import org.slf4j.Logger;
import org.slf4j.LoggerFactory;

import android.app.Notification;
import android.app.NotificationManager;
import android.app.PendingIntent;
import android.content.Intent;
import android.os.IBinder;

import org.flupes.ljf.grannyroomba.ICreateLocomotor;
import org.flupes.ljf.grannyroomba.IServo;
import org.flupes.ljf.grannyroomba.CreateLocomotorStub;
import org.flupes.ljf.grannyroomba.ServoStub;
import org.flupes.ljf.grannyroomba.hw.IoioRoombaCreateLocomotor;
import org.flupes.ljf.grannyroomba.hw.IoioServo;
import org.flupes.ljf.grannyroomba.hw.RoombaCreate;
import org.flupes.ljf.grannyroomba.net.LocomotorServer;
import org.flupes.ljf.grannyroomba.net.ZmqServer;
import org.flupes.ljf.grannyroomba.net.ServoServer;

import ioio.lib.api.DigitalOutput;
import ioio.lib.api.IOIO;
import ioio.lib.api.exception.ConnectionLostException;
import ioio.lib.util.BaseIOIOLooper;
import ioio.lib.util.IOIOLooper;
import ioio.lib.util.android.IOIOService;

public class GrannyRoombaService extends IOIOService {

	protected static Logger s_logger = LoggerFactory.getLogger("grannyroomba");

	protected ZmqServer m_servoService;
	protected IServo m_servoImpl;
	
	protected ZmqServer m_locoService;
	protected ICreateLocomotor m_locoImpl;
	
	protected RoombaCreate m_roomba;

	private DigitalOutput m_greenLed;
	private DigitalOutput m_yellowLed;

	protected static final boolean m_debug = false;

	@Override
	public void onCreate() {
		super.onCreate();	// IOIO things
		/*
		ch.qos.logback.classic.Logger logger =
		        (ch.qos.logback.classic.Logger)LoggerFactory.getLogger("grannyroomba");
		//set its Level to INFO. The setLevel() method requires a logback logger
		logger.setLevel(ch.qos.logback.classic.Level.TRACE);
		 */
		s_logger.info("GrannyRoombaService.onCreate");
		if ( m_debug ) {
			m_servoImpl = new ServoStub(-45, 90, 45);
			m_servoService = new ServoServer(3140, m_servoImpl);
			m_servoService.start();
			
			m_locoImpl = new CreateLocomotorStub();
			m_locoService = new LocomotorServer(3141, m_locoImpl);
			m_locoService.start();
		}
	}

	@Override
	public void onDestroy() {
		s_logger.info("GrannyRoombaService.onDestroy");
		m_servoService.cancel();
		m_locoService.cancel();
		m_roomba.shutdown();
		super.onDestroy();	// IOIO things
	}

	@Override
	public void onStart(Intent intent, int startid) {
		super.onStart(intent, startid);	// IOIO things
		s_logger.info("GrannyRoombaService.onStart");

		NotificationManager nm = (NotificationManager) getSystemService(NOTIFICATION_SERVICE);
		if (intent != null && intent.getAction() != null && intent.getAction().equals("stop")) {
			// User clicked the notification. Need to stop the service.
			nm.cancel(0);
//			stopForeground(false);
			stopSelf();
		}
		else {
			// Service starting. Create a notification.
			Intent stopMsg = new Intent("stop", null, this, this.getClass());
			PendingIntent notifMsg = PendingIntent.getService(this,
					0, stopMsg, PendingIntent.FLAG_UPDATE_CURRENT);

			Notification notification = new Notification.Builder(this)
			.setContentTitle("GrannyRoomba service running...")
			.setContentText("Click Stop to terminate the GrannyRoomba service")
			.setSmallIcon(R.drawable.ic_launcher)
			.addAction(R.drawable.ic_launcher, "Stop", notifMsg)
			.setProgress(0, 0, true)
			.build();

			nm.notify(0, notification);
			// remove nm stuff to enable this
//			startForeground(3141, notification);
		}
	}

	@Override
	public IBinder onBind(Intent intent) {
		s_logger.warn("onBind should not be called!");
		return null;
	}

	@Override
	protected IOIOLooper createIOIOLooper() {
		return new BaseIOIOLooper() {
			private DigitalOutput m_onboardLed;			
			private int count = 0;

			@Override
			protected void setup() throws ConnectionLostException,
			InterruptedException {
				m_onboardLed = ioio_.openDigitalOutput(IOIO.LED_PIN);
				m_yellowLed = ioio_.openDigitalOutput(6);
				m_greenLed = ioio_.openDigitalOutput(12);
				
				if ( ! m_debug ) {
					m_servoImpl = new IoioServo(10, ioio_, 1500, 2000, -180, 180);
					m_servoService = new ServoServer(3140, m_servoImpl);
					m_servoService.start();
					s_logger.info("IOIO looper started the ServoService");
					
					m_roomba = new RoombaCreate(ioio_);
					m_roomba.connect(2, 1);

					m_locoImpl = new IoioRoombaCreateLocomotor(m_roomba);
					m_locoService = new LocomotorServer(3141, m_locoImpl);
					m_locoService.start();
					s_logger.info("IOIO looper started the LocomotorService");
				}
			}

			@Override
			public void loop() throws ConnectionLostException,
			InterruptedException {
				m_onboardLed.write(false);
				m_yellowLed.write(true);
				m_greenLed.write(false);
				Thread.sleep(100);
				m_onboardLed.write(true);
				m_yellowLed.write(false);
				m_greenLed.write(true);
				Thread.sleep(900);
				count += 1;
//				s_logger.info("loop #"+count);
			}
		};
	}

}

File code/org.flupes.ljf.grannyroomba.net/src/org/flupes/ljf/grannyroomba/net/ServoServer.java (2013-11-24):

/*
 * GrannyRoomba - Telepresence robot based on a Roomba and Android tablet
 * Copyright (C) 2013 Lorenzo Flueckiger
 *
 * This file is part of GrannyRoomba.
 *
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
 * You should have received a copy of the GNU General Public License
 * along with GrannyRoomba.  If not, see <http://www.gnu.org/licenses/>.
 */

package org.flupes.ljf.grannyroomba.net;

import org.flupes.ljf.grannyroomba.IServo;
import org.flupes.ljf.grannyroomba.messages.CommandStatusProto.CommandStatus;
import org.flupes.ljf.grannyroomba.messages.CommandStatusProto.CommandStatus.Status;
import org.flupes.ljf.grannyroomba.messages.MotorConfigProto.MotorConfig;
import org.flupes.ljf.grannyroomba.messages.MotorProto.MotorMsg;
import org.flupes.ljf.grannyroomba.messages.MotorStateProto.MotorState;
import org.flupes.ljf.grannyroomba.messages.SingleAxisProto.SingleAxisCmd;
import org.zeromq.ZMQException;

import com.google.protobuf.InvalidProtocolBufferException;

public class ServoServer extends ZmqServer {

	protected IServo m_servo;

	public ServoServer(int port, IServo servo) {
		super(port);
		m_servo = servo;
	}

	IServo getServo() {
		return m_servo;
	}

	@Override
	public void loop() throws InterruptedException {
		boolean response = false;
		SingleAxisCmd cmd = null;
		try {
			byte[] data = m_socket.recv();
			cmd = SingleAxisCmd.parseFrom(data); 
			m_cmdid += 1;
			switch ( cmd.getCmd() ) {

			case SET_MOTOR:
				MotorMsg msg = cmd.getMsg();
				switch ( msg.getMode() ) {
				case CTRL_ABS_POS:
					response = m_servo.setPosition(msg.getPosition());
					break;	
				case CTRL_REL_POS:
					response = m_servo.setPosition(msg.getPosition());
					break;	
				default:	
					s_logger.error("MotorMsg mode "+msg.getMode()+" not supported!");
				} // switch msg.getMode
				CommandStatus.Builder builder = CommandStatus.newBuilder();
				builder.setId(m_cmdid).setStatus(response?Status.COMPLETED:Status.FAILED);
				CommandStatus reply = builder.build();
				m_socket.send(reply.toByteArray());
				break;

			case GET_STATE:
				MotorState state = MotorState.newBuilder().setPosition(m_servo.getPosition()).build();
				m_socket.send(state.toByteArray());
				break;

			case GET_CONFIG:
				float[] limits = m_servo.getLimits(null);
				MotorConfig config = MotorConfig.newBuilder().
						setLowLimit(limits[0]).setHighLimitl(limits[1]).
						build();
				m_socket.send(config.toByteArray());
				break;

			default:
				s_logger.warn("SingleAxisCmd " + cmd.getCmd() + " not supported!");
			} // switch cmd.getCmd
		}
		catch (ZMQException e) {
			//			if ( zmq.ZError.EAGAIN != e.getErrorCode() ) {
			//				s_logger.info("loop received an exception different from EAGAIN -> stop now!");
			//			}
			if ( zmq.ZError.ETERM == e.getErrorCode() ) {
				s_logger.debug("ServoServer received ETERM exception while waiting for command");
				// Mark the service has stopped in case of the ETERM was not issued
				// internally by cancel, but by another process
				//				m_state = State.STOPPED;
			}
			else {
				s_logger.warn("Received unexpected exception: " + e.getErrorCode());
				s_logger.warn("  -> ignore silently for now!");
			}
		}
		catch (InvalidProtocolBufferException e) {
			s_logger.warn("Could not decode SingleAxisCmd message properly!");
			s_logger.warn("  -> ignore silently for now!");
		}
		if ( cmd == null ) {
			s_logger.debug("servo server was interrupted before receiving a command");
		}
	}

	@Override
	public int fini() {
		int ret = super.fini();
		s_logger.info("ServoServer canceled");
		return ret;
	}

}

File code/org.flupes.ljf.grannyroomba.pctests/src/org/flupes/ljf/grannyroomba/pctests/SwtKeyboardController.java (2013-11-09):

/*
 * GrannyRoomba - Telepresence robot based on a Roomba and Android tablet
 * Copyright (C) 2013 Lorenzo Flueckiger
 *
 * This file is part of GrannyRoomba.
 *
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
 * You should have received a copy of the GNU General Public License
 * along with GrannyRoomba.  If not, see <http://www.gnu.org/licenses/>.
 */

package org.flupes.ljf.grannyroomba.pctests;

import java.util.Timer;
import java.util.TimerTask;

import org.apache.log4j.Logger;
import org.eclipse.swt.SWT;
import org.eclipse.swt.events.FocusAdapter;
import org.eclipse.swt.events.FocusEvent;
import org.eclipse.swt.events.KeyEvent;
import org.eclipse.swt.events.KeyAdapter;
import org.eclipse.swt.widgets.Display;
import org.eclipse.swt.widgets.MessageBox;
import org.eclipse.swt.widgets.Shell;
import org.flupes.ljf.grannyroomba.net.CreateLocomotorClient;
import org.flupes.ljf.grannyroomba.net.ServoClient;
import org.flupes.ljf.grannyroomba.RoombaLocomotorModel;

public class SwtKeyboardController {

	static Logger s_logger = Logger.getLogger("grannyroomba");

	private static final float SPEED_INCR = RoombaLocomotorModel.ALLOWED_LINEAR_VELOCITY/5f;
	private static final float SPIN_INCR = RoombaLocomotorModel.ALLOWED_ANGULAR_VELOCITY/5f;

	private static final float TITL_INCR = 5.0f;

	private ServoClient m_servoClient;
	private CreateLocomotorClient m_locoClient;
	private RoombaLocomotorModel m_model;

	private Float m_tilt = null;
	private Float m_minTilt = null;
	private Float m_maxTilt = null;
	private volatile int m_speed;
	private volatile int m_radius;

	private boolean m_connected;
	private Timer m_timer;

	public SwtKeyboardController(ServoClient sclient, CreateLocomotorClient lclient) {
		m_servoClient = sclient;
		m_locoClient = lclient;
		m_model = new RoombaLocomotorModel(m_locoClient);

		float limits[] = m_servoClient.getLimits(null);
		if ( limits == null ) {
			s_logger.error("Could not get servo position limits!");
		}
		else {
			m_minTilt = limits[0];
			m_maxTilt = limits[1];
			s_logger.info("Tilt limits: [" + m_minTilt + ", " + m_maxTilt + "]");
		}
		m_tilt = m_servoClient.getPosition();
		if ( m_tilt == null ) {
			s_logger.error("Could not get current servo position!");
		}
		else {
			s_logger.info("Tilt current position: " + m_tilt);
		}

		m_connected = true;
		
		m_timer = new Timer();
		TimerTask task = new TimerTask() {
			@Override
			public void run() {
				try {
					int ret = m_locoClient.getStatus();
					if ( ret < 0 ) {
						s_logger.error("getStatus REQ/REP in Timer thread failed after timeout");
						stop();
					}
					else {
						// Reset the speed and spin if the robot was stopped.
						// otherwise just ignore the current velocity
						// and radius, assuming that the robot would have
						// always done what ask!
						//				s_logger.debug("Velocity="+m_locoClient.getVelocity()
						//						+" / Radius="+m_locoClient.getRadius());
						m_speed = m_locoClient.getVelocity();
						m_radius = m_locoClient.getRadius();
						if ( m_speed == 0 ) {
							m_model.reset(0, m_model.getSpin());
						}
						if ( m_radius == 0x8000 ||
								m_locoClient.getBumps() == 0x7FFF ) {
							m_model.reset(m_model.getSpeed(), 0);
						}
					}
				} catch (Exception exception) {
					s_logger.error("getStatus REQ/REP in Timer thread failed for an unknown reason");
					s_logger.debug(exception);
					stop();
				}
			}
		};
		m_timer.schedule(task, 50, 500);
	}

	public boolean connected() {
		return m_connected;
	}

	public KeyAdapter controller() {
		return new ControlListener();
	}

	public FocusAdapter stopper() {
		return new FocusLost();
	}

	public void cancel() {
		m_connected = false;
		m_timer.cancel();
	}

	protected void stop() {
		s_logger.warn("stoping the keyboard controller and send a popup notification");
		m_timer.cancel();
		Display.getDefault().asyncExec(new Runnable() {
			public void run() {
				Shell[] shells = Display.getDefault().getShells();
				if ( shells.length < 1 ) {
					s_logger.error("Could not find a parent shell!");
				}
				else {
					if ( shells.length > 1 ) {
						s_logger.warn("More than one shell for this simple UI?");
					}
					MessageBox msg = new MessageBox(shells[0], SWT.OK);
					msg.setMessage("Connection to GrannyRoomba interrupted!\nThe application will terminate now.\nYou can try to restart it when the robot is up again.");
					msg.open();
				}
				m_connected = false;
			}
		});
	}

	class FocusLost extends FocusAdapter {
		@Override
		public void focusLost(FocusEvent e) {
			s_logger.info("Lost focus -> stop the robot!");
			try {
				m_model.stop();
			} catch (Exception exception) {
				s_logger.error("REQ/REP failed for focusLost");
				s_logger.debug(exception);
				stop();
			}
		}
	}

	class ControlListener extends KeyAdapter {

		@Override
		public void keyPressed(KeyEvent e) {
			if (!m_connected) return;
			try {
				boolean ret;
				switch (e.keyCode) {
				case SWT.PAGE_UP:
				case 'h':					
					m_tilt += TITL_INCR;
					if ( m_tilt > m_maxTilt ) {
						m_tilt = m_maxTilt;
					}
					ret = m_servoClient.setPosition(m_tilt);
					s_logger.info("PAGE_UP -> setPosition("+m_tilt+") => "+((ret)?"true":"false"));
					break;
				case SWT.PAGE_DOWN:
				case 'b':
					m_tilt -= TITL_INCR;
					if ( m_tilt < m_minTilt ) {
						m_tilt = m_minTilt;
					}
					ret = m_servoClient.setPosition(m_tilt);
					s_logger.info("PAGE_DOWN -> setPosition("+m_tilt+") => "+((ret)?"true":"false"));
					break;
				case SWT.ARROW_UP:
					m_model.incrementVelocity(SPEED_INCR);
					break;
				case SWT.ARROW_DOWN:
					m_model.incrementVelocity(-SPEED_INCR);
					break;
				case SWT.ARROW_RIGHT:
					m_model.incrementSpin((Math.abs(m_speed)<SPEED_INCR/2)?-SPIN_INCR:-SPIN_INCR/4);
					break;
				case SWT.ARROW_LEFT: 
					m_model.incrementSpin((Math.abs(m_speed)<SPEED_INCR/2)?SPIN_INCR:SPIN_INCR/4);
					break;
				case SWT.SPACE:
					m_model.stop();
					break;
				case SWT.CTRL:
					s_logger.trace("CONTROL pressed -> print telemetry");
					s_logger.info("  Velocity = " + m_speed);
					s_logger.info("  Radius = " + m_radius);
					m_tilt = m_servoClient.getPosition();
					if ( m_tilt != null ) {
						s_logger.info("  Tilt angle = " + m_tilt);
					}
					else {
						s_logger.warn("  invalid position returned!");
					}
					break;

				default:
					// just ignore silently
				}
			} catch (Exception exception) {
				s_logger.error("REQ/REP failed for getStatus in keyPressed processing");
				s_logger.debug(exception);
				stop();
			}
		}
	}

}

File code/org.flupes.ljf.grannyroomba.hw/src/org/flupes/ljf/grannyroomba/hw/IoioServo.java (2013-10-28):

/*
 * GrannyRoomba - Telepresence robot based on a Roomba and Android tablet
 * Copyright (C) 2013 Lorenzo Flueckiger
 *
 * This file is part of GrannyRoomba.
 *
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
 * You should have received a copy of the GNU General Public License
 * along with GrannyRoomba.  If not, see <http://www.gnu.org/licenses/>.
 */

package org.flupes.ljf.grannyroomba.hw;

import ioio.lib.api.DigitalOutput;
import ioio.lib.api.IOIO;
import ioio.lib.api.PwmOutput;
import ioio.lib.api.DigitalOutput.Spec.Mode;
import ioio.lib.api.exception.ConnectionLostException;

import org.flupes.ljf.grannyroomba.IServo;
import org.slf4j.Logger;
import org.slf4j.LoggerFactory;

public class IoioServo implements IServo {

	public static final int DEFAULT_CENTER_PULSE_WIDTH = 1500;
	public static final int DEFAULT_PULSE_RANGE = 1000;
	public static final int DEFAULT_LOW_LIMIT = -90;
	public static final int DEFAULT_HIGH_LIMIT = 90;

	public final int m_servoPin;
	public final int m_centerPulseWidth;
	public final int m_pulseRange;
	public final float m_lowLimitDegrees;
	public final float m_highLimitDegrees;
	
	protected IOIO m_ioio;
	protected int m_calibrationOffset;
	protected float m_currentPositionDegrees;
	protected PwmOutput m_servoPwmOutput;
	protected final int PWM_FREQ = 100;

	protected static Logger s_logger = LoggerFactory.getLogger("grannyroomba");

	public IoioServo(int ctrlPin, IOIO ioio) {
		m_servoPin = ctrlPin;
		m_centerPulseWidth = DEFAULT_CENTER_PULSE_WIDTH;
		m_pulseRange = DEFAULT_PULSE_RANGE;
		m_lowLimitDegrees = DEFAULT_LOW_LIMIT;
		m_highLimitDegrees = DEFAULT_HIGH_LIMIT;
		m_calibrationOffset = 0;
		m_ioio = ioio;
		init();
	}
	
	public IoioServo(int ctrlPin, IOIO ioio, int center, int range, float low, float high) {
		m_servoPin = ctrlPin;
		m_centerPulseWidth = center;
		m_pulseRange = range;
		m_lowLimitDegrees = low;
		m_highLimitDegrees = high;
		m_calibrationOffset = 0;
		m_ioio = ioio;
		init();
	}
	
	protected boolean init() {
		while ( m_ioio == null ) {
			s_logger.info("Waiting for IOIO to come up...");
			try {
				Thread.sleep(1000);
			} catch (InterruptedException e) {
				// TODO Auto-generated catch block
				e.printStackTrace();
			}
		}
		try {
			m_servoPwmOutput = m_ioio.openPwmOutput(new DigitalOutput.Spec(m_servoPin, Mode.OPEN_DRAIN), PWM_FREQ);
			m_currentPositionDegrees = 0;
			m_servoPwmOutput.setPulseWidth(position2pulse(m_currentPositionDegrees));
		} catch (ConnectionLostException e) {
			e.printStackTrace();
			return false;
		}
		return true;
	}
	
	public void setCalibrationOffset(int offset) {
		m_calibrationOffset = offset;
	}
	
	public int getCalibrationOffset() {
		return m_calibrationOffset;
	}

	@Override
	synchronized public Float getPosition() {
		return m_currentPositionDegrees;
	}

	@Override
	public float[] getLimits(float[] store) {
		if ( store == null ) {
			store = new float[2];
		}
		store[0] = m_lowLimitDegrees;
		store[1] = m_highLimitDegrees;
		return store;
	}

	@Override
	public synchronized boolean setPosition(float position) {
		if ( m_ioio == null ) return false;
		if ( m_lowLimitDegrees <= position && position <= m_highLimitDegrees ) {
			try {
				m_servoPwmOutput.setPulseWidth(position2pulse(position));
			} catch (ConnectionLostException e) {
				e.printStackTrace();
				return false;
			}
			m_currentPositionDegrees = position;
			return true;
		}
		return false;
	}

	@Override
	public synchronized boolean changePosition(float offset) {
		return setPosition(m_currentPositionDegrees+offset);
	}

	protected int position2pulse(float position) {
		return m_centerPulseWidth + m_calibrationOffset 
		+(int)(m_pulseRange*position/(m_highLimitDegrees-m_lowLimitDegrees));

	}
}

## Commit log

2013-05-05 Telemetry framework mostly in place
2013-05-05 Started to have a keystroke listener. Finally use Swing because the IOIO application does not connect to the board even if not SWT code is called, but the SWT bundle added as a dependency!
2013-05-06 Improved steering using curvature
2013-05-12 Created a sample set of messages with protobuff
2013-06-08 first prototype BOM
2013-07-10 Added a message for a simple motor
2013-07-15 Added third-party libraries to simplify the workspace creation and keep track of the necessary mods.
2013-08-25 First functional test with client/server - created a general Server and Client - created an IServo interface (to be used with MotorCmd) - created a ServoServer and ServoClient - created a KeyboardCon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
2013-08-26 First Servo Service running on Android and listening to Motor messages. The basics seems to work but the service cannot be restarted (context exception).
2013-08-26 Restore the correct path for the libraries and try to debug more... No success: the context is re-created at the second launch, but a new socket using this context cannot (it still feels the context 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
2013-08-27 Created an interface for a SingleAxis motor, together with messages to report state and config
2013-08-27 Fully implemented the Servo client interface as well as a complete Servo stub server
2013-08-27 Functional test commanding and querying a stub servo sever on Android from a keyboard controller
2013-08-29 Create a servo class based on ioio and try to use the usb accessory mode
2013-08-30 Successful demo controlling the servo remotely: - IOIO board plugged on custom shield powered by the Roomba - Nexus7 connected with a USB cable and micro-A adapter to the IOIO - Nexus7 with wifi conn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
2013-08-31 First working prototype! (it was so quick after all the Eclipse/Android dependencies hurdles).
    This is a very cool first demo that put all the components together:
    Nexus-7 secured on the tilt system mounted on the Roomba create and
    connected to the IOIO with custom shield.
    Skype running on the tablet for visual feedback
    Issues:
    - Service notification "stop" button does not appear anymore when there
    are more notifications (hard to stop the service)
    - The system seems to stop responding after a while (only 2 runs so far,
    so no clue yet)
    - Everything configuration wise (ip, ports, pin) is hard-coded
    - PageUp/PageDown (used for tilt control) do not exist as real key on a
    laptop keyboard
    - Drive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
    [GrannyRoombaKeyboardUi.java, GrannyRoombaService.java, KeyboardController.java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]
2013-09-03 Added diagram of my mini board to power the IOIO from Roomba and to communicate with the appropriate lines.
2013-09-09 avoid to spin in place to fast
    [GrannyRoombaKeyboardUi.java]
2013-09-09 more the hardware thing in a separate project (workaround for IOIO Lib PC/Android bad dependencies
    [IoioServo.java, RoombaSeries400.java, SerialIoioRoomba.java]
2013-09-09 Broke down GrannyRoomba even more to manage the dependencies better
    [LocomotorClient.java, LocomotorServer.java, ServoClient.java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]
2013-09-09 added a specific project for ioio stuff from PC because having it in a plugin depending on SWT simlpy prevent IOIO to boot\!
    [KeyboardController.java]
2013-09-28 Hide the threading using an inner Runnable class
2013-09-29 I hate Eclipse (spending most of my time configuring the framework rather than coding, and upgrading to Kepler did not help
2013-09-30 Optimized considerably the telemetry reading/processing (it is working) Got read of 2 intermediates data structures (too bad IOIO does not exposes its internal buffer supporting the Serial Input Stre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
2013-10-10 Two improvements: 1) Fix a bug to terminate correctly: need to disconnect the socket first 2) Set timeout on the send / recv to avoid being blocked if the server dies 3) Try to encapsulate the req/re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
2013-10-10 Augmented to include a stub Locomotor (only stub Servo before).
2013-10-11 use the velocity/radius feedback to reset the interal speed/spin of the controller
    [GrannyRoombaKeyboardUi.java, KeyboardController.java]
2013-10-12 corrected bug in the case statement
    [LocomotorServer.java]
2013-10-12 generate exceptions when the req/rep did not work correctly
    [RoombaLocomotorClient.java]
2013-10-12 abort the telemetry querying and provides a termination message when something went wrong in the communication
    [KeyboardController.java]
2013-10-12 use the new graphic and stop correctly the getStatus thread when exiting by closing the window
    [GrannyRoombaKeyboardUi.java, KeyboardController.java]
2013-10-14 stop on exit and avoid simulateneous access to the socket while canceling
    [SwtKeyboardController.java]
2013-10-14 more info on error
    [GrannyRoombaKeyboardUi.java]
2013-10-14 created a hw directory, moved the BOM there, and added some pictures
2013-10-16 Added a class in progress (unused yet) before loosing track of it
2013-10-16 Implement velocityDrive using directDrive and include validity check
2013-10-16 computes the derived velocity/radius when the last command was a direct drive (rigth+left wheel speeds)
2013-10-16 moved the socket thread safety in the client itself (it was before on the user side)
2013-10-18 reduced the allowed linear velocity to 30cm/s
2013-10-28 added the plates drawings (for laser cutting)
    [GrannyRoombaPlates.dxf, GrannyRoombaPlates.skp]
2013-10-28 update the readme on landing page
2013-11-03 Use the ZmqClient reqrep pattern rather the local (and wrong) one
    [CreateLocomotorClient.java]
2013-11-03 Made non-blocking / resilient to network failures
    [SwtKeyboardController.java]
2013-11-09 Use the ZmqClient reqrep pattern to handle network issue correctly
    [ServoClient.java]
2013-11-12 remove old printout
2013-11-12 Major revision: telemetry on request + clean shutdown
    1) A new mode for telemetry has been implemented because it seems that the
    streaming cannot be always processed in a timely manner on a Android
    device (works fine on a PC). The new mode is asking for a single telemetry
    message, then reads it, and repeat (there is currently a sleep to limit
    the number of request per seconds).
    2) A new "shutdown" method allow to terminate cleanly the various threads.
2013-11-17 added LEDS command (+MOTORS that we will never use)
2013-11-17 new method to control the roomba leds
2013-11-17 replaced the monitorSafety thread with a simple watchdog + show some information with leds
2013-11-18 move the usb accessory intent to the application (was in service), making the controller start automatically when the power is turned on
2013-11-24 play with the two new leds I added on the IOIO-Roomba adapter board
2013-12-23 change the mapping for tilt angle to hat button (replaced by speed control)
2013-12-23 put more items in the BOM

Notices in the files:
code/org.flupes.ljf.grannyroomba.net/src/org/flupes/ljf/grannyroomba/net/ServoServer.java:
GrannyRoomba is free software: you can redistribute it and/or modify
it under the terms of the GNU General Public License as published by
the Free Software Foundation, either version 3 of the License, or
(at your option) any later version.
